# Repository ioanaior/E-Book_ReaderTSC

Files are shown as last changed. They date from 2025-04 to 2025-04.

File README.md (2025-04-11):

# E-Book_ReaderTSC

## 📘 Schema bloc

```mermaid
flowchart TB
  USB-C -->|5V| Charger["Battery Charger (MCP73832)"]
  Charger -->|Charging| LiPo["LiPo Battery"]
  LiPo --> LDO["3V3 LDO"]
  LiPo --> DC5["5V DC/DC"]

  ESP32["ESP32-C3-WROOM"]

  LDO -->|3.3V| ESP32
  LDO -->|3.3V| Display
  LDO -->|3.3V| SDCard
  LDO -->|3.3V| TempSensor
  LDO -->|3.3V| Buttons

  ESP32 -- SPI --> Display["1.5'' E-Ink Display (200x200px)"]
  ESP32 -- SPI --> SDCard["SD Card"]
  ESP32 -- GPIO --> Buttons["Buttons (3x)"]
  ESP32 -- I2C --> TempSensor["Temp/RH Sensor (BME680)"]
  ESP32 -- USB --> USB-C
```

# List of Components

Aici sunt listate componentele, impreuna cu linkurile pentru a verifica preturile si fisele tehnice. Unele componente nu au un model specificat, si în acele cazuri, fisele tehnice si linkurile catre preturi sunt marcate ca `#N/A`.
+ also SJ-ul si TP-urile sunt modelate de mine, deci nu am importat model 3D.

| Name of component  | Device | Check Prices | DataSheet |
|---|---|---|---|
| BOOT_BUTTON | BUTTON_CUSYOMV1 | [Check Price](https://industry.panasonic.com/global/en/products/control/switch/light-touch/number/evqpuj02k)  | [DataSheet](https://industry.panasonic.com/global/en/products/control/switch/light-touch/number/evqpuj02k) |
| C1 | ESP32_WROVER_EAGLE-LTSPICE_CC0402 | [Check Price](https://industry.panasonic.com/global/en/products/control/switch/light-touch/number/evqpuj02k)  | [DataSheet](https://industry.panasonic.com/global/en/products/control/switch/light-touch/number/evqpuj02k) |
| C1_BAT | ESP32_WROVER_EAGLE-LTSPICE_CC0402 | #N/A | #N/A |
| C1_BAT1 | EAGLE-LTSPICE_CC0402 | #N/A | #N/A |
| C1_BAT2 | EAGLE-LTSPICE_CC0402 | #N/A | #N/A |
| C2 | ESP32_WROVER_EAGLE-LTSPICE_CC0402 | #N/A | #N/A |
| C2_BAT | ESP32_WROVER_EAGLE-LTSPICE_CC0402 | #N/A | #N/A |
| C3 | RCL_CPOL-EUCT3528 | #N/A | #N/A |
| C4 | ESP32_WROVER_EAGLE-LTSPICE_CC0402 | #N/A | #N/A |
| C4_USB | ESP32_WROVER_EAGLE-LTSPICE_CC0402 | #N/A | #N/A |
| C5 | ESP32_WROVER_EAGLE-LTSPICE_CC0402 | #N/A | #N/A |
| C5_USB | ESP32_WROVER_EAGLE-LTSPICE_CC0402 | #N/A | #N/A |
| C6 | ESP32_WROVER_EAGLE-LTSPICE_CC0402 | #N/A | #N/A |
| C7 | ESP32_WROVER_EAGLE-LTSPICE_CC0402 | #N/A | #N/A |
| C8 | ESP32_WROVER_EAGLE-LTSPICE_CC0402 | #N/A | #N/A |
| C9 | EAGLE-LTSPICE_CC0402 | #N/A | #N/A |
| C10 | ESP32_WROVER_EAGLE-LTSPICE_CC0402 | #N/A | #N/A |
| C10_SUPERCAP | CPH3225A | [Check Price](https://www.snapeda.com/parts/CPH3225A/Seiko+Instruments/view-part/?ref=eda) | [DataSheet](https://www.snapeda.com/parts/CPH3225A/Seiko+Instruments/view-part/?ref=eda) |
| CHANGE_BUTTON | BUTTON_CUSYOMV1 | [Check Price](https://industry.panasonic.com/global/en/products/control/switch-light-touch/number/evqpuj02k)  | [DataSheet](https://industry.panasonic.com/global/en/products/control/switch-light-touch/number/evqpuj02k) |
| CHG_LED | ADAFRUIT_LEDCHIP-LED0603 | [Check Price](https://www.snapeda.com/parts/KP-1608SURCK/Kingbright/view-part/?ref=search&t=LED%200603) | [DataSheet](https://www.snapeda.com/parts/KP-1608SURCK/Kingbright/view-part/?ref=search&t=LED%200603) |
| C_DELAY | ESP32_WROVER_EAGLE-LTSPICE_CC0402 | #N/A | #N/A |
| D1 | USBLC6-2SC6Y | [Check Price](https://www.snapeda.com/parts/USBLC6-2SC6Y/STMicroelectronics/view-part/?ref=eda) | [DataSheet](https://www.snapeda.com/parts/USBLC6-2SC6Y/STMicroelectronics/view-part/?ref=eda) |
| D2 | ESP32_WROVER_AVX---SD0805S020S1R0_AVX_... | [Check Price](https://eu.mouser.com/ProductDetail/KYOCERA-AVX/SD0805S020S1R0?qs=jCA%252BPfw4LHbpkAoSnwrdjw%3D%3D) | [DataSheet](http://datasheets.avx.com/schottky.pdf) |
| D3 | MBR0530 | [Check Price](https://eu.mouser.com/ProductDetail/KYOCERA-AVX/SD0805S020S1R0?qs=jCA%252BPfw4LHbpkAoSnwrdjw%3D%3D) | [DataSheet](https://eu.mouser.com/ProductDetail/KYOCERA-AVX/SD0805S020S1R0?qs=jCA%252BPfw4LHbpkAoSnwrdjw%3D%3D) |
| D4 | MBR0530 | [Check Price](https://www.snapeda.com/parts/MBR0530/Onsemi/view-part/?ref=eda) | [DataSheet](https://www.snapeda.com/parts/MBR0530/Onsemi/view-part/?ref=eda) |
| D5 | MBR0530 | [Check Price](https://www.snapeda.com/parts/MBR0530/Onsemi/view-part/?ref=eda) | [DataSheet](https://www.snapeda.com/parts/MBR0530/Onsemi/view-part/?ref=eda) |
| D6 | PGB1010603MR | [Check Price](https://www.snapeda.com/parts/PGB1010603MR/Littelfuse/view-part/?ref=eda) | [DataSheet](https://www.snapeda.com/parts/PGB1010603MR/Littelfuse/view-part/?ref=eda) |
| D7 | ESP32_WROVER_AVX---SD0805S020S1R0_AVX_... | [Check Price](https://eu.mouser.com/ProductDetail/KYOCERA-AVX/SD0805S020S1R0?qs=jCA%252BPfw4LHbpkAoSnwrdjw%3D%3D) | [DataSheet](http://datasheets.avx.com/schottky.pdf) |
| D8 | PGB1010603MR | [Check Price](https://www.snapeda.com/parts/PGB1010603MR/Littelfuse/view-part/?ref=eda) | [DataSheet](https://www.snapeda.com/parts/PGB1010603MR/Littelfuse/view-part/?ref=eda) |
| D9 | PGB1010603MR | [Check Price](https://www.snapeda.com/parts/PGB1010603MR/Littelfuse/view-part/?ref=eda) | [DataSheet](https://www.snapeda.com/parts/PGB1010603MR/Littelfuse/view-part/?ref=eda) |
| D10 | PGB1010603MR | [Check Price](https://www.snapeda.com/parts/PGB1010603MR/Littelfuse/view-part/?ref=eda) | [DataSheet](https://www.snapeda.com/parts/PGB1010603MR/Littelfuse/view-part/?ref=eda) |
| D11 | PGB1010603MR | [Check Price](https://www.snapeda.com/parts/PGB1010603MR/Littelfuse/view-part/?ref=eda) | [DataSheet](https://www.snapeda.com/parts/PGB1010603MR/Littelfuse/view-part/?ref=eda) |
| D12 | PGB1010603MR | [Check Price](https://www.snapeda.com/parts/PGB1010603MR/Littelfuse/view-part/?ref=eda) | [DataSheet](https://www.snapeda.com/parts/PGB1010603MR/Littelfuse/view-part/?ref=eda) |
| EPD_C1 | ESP32_WROVER_EAGLE-LTSPICE_CC0402 | #N/A | #N/A |
| EPD_C2 | ESP32_WROVER_EAGLE-LTSPICE_CC0402 | #N/A | #N/A |
| EPD_C5 | ESP32_WROVER_EAGLE-LTSPICE_CC0402 | #N/A | #N/A |
| EPD_C6 | ESP32_WROVER_EAGLE-LTSPICE_CC0402 | #N/A | #N/A |
| EPD_C7 | ESP32_WROVER_EAGLE-LTSPICE_CC0402 | #N/A | #N/A |
| EPD_C8 | ESP32_WROVER_EAGLE-LTSPICE_CC0402 | #N/A | #N/A |
| EPD_C9 | ESP32_WROVER_EAGLE-LTSPICE_CC0402 | #N/A | #N/A |
| EPD_C10 | ESP32_WROVER_EAGLE-LTSPICE_CC0402 | #N/A | #N/A |
| EPD_C11 | ESP32_WROVER_EAGLE-LTSPICE_CC0402 | #N/A | #N/A |
| EPD_C12 | ESP32_WROVER_EAGLE-LTSPICE_CC0402 | #N/A | #N/A |
| IC1 | BD5229G-TR | [Check Price](https://componentsearchengine.com/part-view/BD5229G-TR/ROHM%20Semiconductor) | [DataSheet](https://componentsearchengine.com/part-view/BD5229G-TR/ROHM%20Semiconductor) |
| IC4 | XC6220A331MR-G | [Check Price](https://componentsearchengine.com/part-view/XC6220A331MR-G/Torex) | [DataSheet](https://componentsearchengine.com/part-view/XC6220A331MR-G/Torex) |
| J1 | FH34SRJ-24S-0.5SH_99_ | [Check Price](https://componentsearchengine.com/part-view/XC6220A331MR-G/Torex) | [DataSheet](https://componentsearchengine.com/part-view/XC6220A331MR-G/Torex) |
| J2 | SAMACSYS_PARTS_USB4110-GF-A | [Check Price](https://componentsearchengine.com/part-view/USB4110-GF-A/GCT%20(GLOBAL%20CONNECTOR%20TECHNOLOGY)) | [DataSheet](https://componentsearchengine.com/part-view/USB4110-GF-A/GCT%20(GLOBAL%20CONNECTOR%20TECHNOLOGY)) |
| J3 | QWIIC_CONNECTORJS-1MM | #N/A | #N/A |
| J4 | 112A-TAAR-R03_ATTEND | [Check Price](https://store.comet.srl.ro/Catalogue/Product/43497/) | [DataSheet](https://store.comet.srl.ro/Catalogue/Product/43497/) |
| L1 | 744043680IND_4828-WE-TPC_WRE | [Check Price](https://eu.mouser.com/ProductDetail/Wurth-Elektronik/744043680?qs=PGXP4M47uW6VkZq%252BkzjrHA%3D%3D) | [DataSheet](https://eu.mouser.com/ProductDetail/Wurth-Elektronik/744043680?qs=PGXP4M47uW6VkZq%252BkzjrHA%3D%3D) |
| PFMF.050.1 | ESP32C6_VARISTORCN1812 | [Check Price](https://www.mouser.co.uk/ProductDetail/EPCOS-TDK/B72520T0350K062?qs=dEfas%2FXlABIszF52uu7vrg%3D%3D) | [DataSheet](https://www.mouser.co.uk/ProductDetail/EPCOS-TDK/B72520T0350K062?qs=dEfas%2FXlABIszF52uu7vrg%3D%3D) |
| Q1 | ESP32_WROVER_SPARKFUN-DISCRETESEMI_MOSFET_... | [Check Price](https://componentsearchengine.com/part-view/DMG2305UX-7/Diodes%20Incorporated) | [DataSheet](https://componentsearchengine.com/part-view/DMG2305UX-7/Diodes%20Incorporated) |
| Q2 | ESP32_WROVER_SPARKFUN-DISCRETESEMI_MOSFET_... | #N/A | #N/A |
| Q3 | D8 | [Check Price](https://componentsearchengine.com/part-view/PGB1010603MR/Littelfuse) | [DataSheet](https://componentsearchengine.com/part-view/PGB1010603MR/Littelfuse) |
| Q4 | Q2_TS-B2_REACHPACK | #N/A | #N/A |

Detalii despre functionalitatea hardware

### Microcontroller – ESP32-C3-WROOM
Microcontroller-ul utilizat este ESP32-C3-WROOM, un procesor 32-bit RISC-V, care ruleaza la frecvente de pana la 160MHz. Acesta dispune de 512KB de SRAM intern si 8MB de flash extern, suficiente pentru a sustine aplicatii complexe. ESP32-C3-WROOM beneficiaza de conectivitate Wi-Fi 6 si Bluetooth 5, facilitand conexiuni rapide si stabile. Printre perifericele sale se numara SPI, I²C, UART si GPIO multiple, iar pentru economisirea energiei, dispune de moduri de tip sleep si deep sleep.

### Ecran E-Paper (1.5 inch)
Ecranul e-paper utilizat are o rezolutie de 200x200px si comunica cu ESP32 prin interfata SPI cu 4 pini (CS, DC, RST, BUSY). Desi consumul de energie este foarte redus in timpul afisarii statice, la fiecare refresh al imaginii ecranul necesita aproximativ 15–25mA, in functie de modul de actualizare ales. Acest tip de afisaj este ideal pentru aplicatiile de tip e-reader, datorita consumului minim de energie in mod static.

### Senzor de mediu – BME680
Senzorul BME680 masoara temperatura, umiditatea, presiunea si calitatea aerului (VOC/eCO2). Acesta comunica cu microcontroller-ul prin I²C la 400kHz, iar consumul in modul standby este de doar 2.1µA, crescand pana la cativa mA in timpul masurarilor. BME680 este o alegere excelenta datorita capacitatii sale de a integra multiple tipuri de masuratori intr-un singur cip, oferind date importante pentru monitorizarea mediului.

### Gestionarea energiei – Baterie Li-Po si IC de incarcare
Dispozitivul este alimentat de o baterie Li-Po de 2500mAh, care ofera o autonomie extinsa. IC-ul de incarcare MCP73832, compatibil cu incarcarea prin USB-C, permite incarcarea bateriei cu un curent de pana la 1A. Monitorizarea nivelului bateriei se face prin intermediul unui fuel gauge MAX17048, care transmite informatii despre tensiune si stare prin I²C. Pentru a asigura o tensiune stabila de 3.3V, se foloseste un regulator LDO XC6220A331MR-G, care alimenteaza microcontroller-ul si celelalte componente.

### Butoane tactile pentru interactiune
Dispozitivul dispune de trei butoane tactile pentru navigarea prin meniu, selectarea optiunilor si schimbarea paginilor. Fiecare buton este conectat la un GPIO al microcontroller-ului printr-un circuit de debouncing, care asigura o interactiune fiabila. Debouncing-ul poate fi implementat fie hardware, printr-o combinatie de rezistor si condensator, fie in firmware.

### Port USB-C
Portul USB-C permite atat incarcarea bateriei, cat si transferul de date. Acesta poate fi utilizat si pentru actualizari de firmware prin bootloader sau OTA prin Wi-Fi. Protectiile incluse (ESD si rezistente de terminare) asigura o protectie suplimentara impotriva eventualelor probleme de conectivitate.

### Conector Qwiic (I²C)
Conectorul Qwiic standardizat, cu patru pini (VCC, GND, SDA, SCL), faciliteaza integrarea rapida a modulelor I²C externe. Acesta este ideal pentru extinderea dispozitivului cu senzori suplimentari sau pentru prototipuri rapide.

### Card SD pentru stocare externa
Dispozitivul include un conector pentru card SD, permitand stocarea de e-book-uri, loguri sau fisiere pentru actualizari de firmware. Interfata poate fi configurata in modul SD (1-bit/4-bit) sau SPI, in functie de necesitatile firmware-ului.

### RTC DS3231
RTC-ul DS3231 asigura un ceas de timp real precis si mentine timpul chiar si atunci cand dispozitivul nu este alimentat, datorita unei baterii secundare sau supercondensatorului de backup. Comunicarea cu microcontroller-ul se face prin I²C.

### Memorie externa Flash (W25Q512JVEIQ)
Memoria flash externa W25Q512JVEIQ, conectata prin SPI dedicat (quad SPI), este utilizata pentru stocarea firmware-ului si a fisierelor mari (e-book-uri, etc.). Acesta permite o incarcare rapida a datelor si o capacitate mare de stocare.

### Comunicare si interfete
Dispozitivul utilizeaza diverse interfete pentru a comunica cu componentele sale:

- **SPI**: Ecranul e-paper si memoria flash externa utilizeaza SPI pentru comunicare.
- **I²C**: Senzorul BME680, fuel gauge MAX17048, RTC DS3231 si conectorul Qwiic sunt conectate prin I²C.
- **USB-C**: Transfer de date si alimentare.
- **GPIO**: Butoane tactile si semnale de control pentru display.

### Estimarea consumului de energie
- **ESP32-C3-WROOM** (activ): ~80mA (Wi-Fi activ) / < 10mA (idle)
- **E-Paper (refresh)**: ~15–25mA (doar in timpul refresh-ului)
- **BME680** (activ): ~3.6mA (peak) / 2.1µA (sleep)
- **MAX17048 (fuel gauge)**: ~50µA
- **DS3231 (RTC)**: ~3.5mA (activ) / <1µA (back-up)
- **MCP73832 (charger)**: Depinde de curentul de incarcare

In modul Deep Sleep, consumul total scade sub 50-100µA, iar in utilizare activa cu Wi-Fi si actualizari frecvente ale ecranului, consumul poate ajunge la 100-150mA.

Cu o baterie de 2500mAh, dispozitivul poate avea o autonomie de cateva saptamani in regim normal de utilizare, in care majoritatea timpului este in stare inactiva si doar afiseaza imagini statice.

## Detalierea pinilor ESP32-C6 utilizati pentru fiecare componenta

| Pin ESP32-C6  | Componenta / Semnal | Explicatie |
|---|---|---|
| GPIO1 | I²C SDA (BME688, MAX17048, DS3231, Qwiic) | Se foloseste pentru a partaja magistrala I²C intre toti senzorii si RTC. |
| GPIO2 | I²C SCL (BME688, MAX17048, DS3231, Qwiic) | Linia de clock pentru comunicarea I²C. |
| GPIO5 | SPI MISO (E-Paper) | Pinul pentru citirea datelor sau a statusului de la ecranul e-paper. |
| GPIO6 | SPI MOSI (E-Paper) | Trimiterea datelor catre ecranul e-paper. |
| GPIO7 | SPI CLK (E-Paper) | Semnal de clock pentru sincronizarea cu e-paper. |
| GPIO8 | SPI CS (E-Paper) | Chip Select pentru a activa comunicarea cu e-paper.  |
| GPIO9 | E-Paper DC (Data/Command) | Semnal pentru a diferentia intre date si comenzi pentru ecranul e-paper. |
| GPIO10 | E-Paper RST | Pinul de reset hardware pentru e-paper. |
| GPIO11 | E-Paper BUSY | Intrare din display care indica daca ecranul este ocupat sau nu. |
| GPIO12 | Button #1 | Intrare digitala pentru primul buton (ex. pagina urmatoare). |
| GPIO13 | Button #2 | Intrare digitala pentru al doilea buton (ex. pagina anterioara). |
| GPIO14 | Button #3 | Intrare digitala pentru al treilea buton (ex. Meniu/OK). |
| GPIO15 | MAX17048 ALERT (optional) | Semnal de alerta de la MAX17048 pentru nivel scazut al bateriei. |
| GPIO16 | USB D+ (intern la USB PHY) | Pin dedicat pentru semnalul USB 2.0 (D+). |
| GPIO17 | USB D- (intern la USB PHY) | Pin dedicat pentru semnalul USB 2.0 (D-). |
| GPIO18 | LED de status (optional) | Indicator pentru diverse stari (ex. Wi-Fi, incarcare, etc.). |
| GPIO19 | SD Card CS (optional) | Chip Select pentru cardul SD (daca se foloseste SPI). |
| GPIO20 | SD Card MISO (optional) | Intrare date de la cardul SD. |
| GPIO21 | SD Card MOSI (optional) | Iesire date catre cardul SD. |
| GPIO4 | SD Card CLK (optional) | Semnal de clock pentru cardul SD (SPI). |

## Concluzii

Acest proiect a fost un adevarat challenge si a implicat o cantitate considerabila de munca. Au existat momente cand m-am simtit complet depasita, iar uneori chiar enervata de complexitatea sa :)) Cu toate acestea, am reusit sa-l finalizez si sunt destul de multumita de rezultat. 
Sper ca totul este in regula si ca nu mi-a scapat vreun detaliu prea important. Ca orice proiect de acest tip, a fost o experienta de invatare continua, iar daca voi gasi ceva ce nu am luat in considerare, il voi imbunatati pe parcurs.😅<3

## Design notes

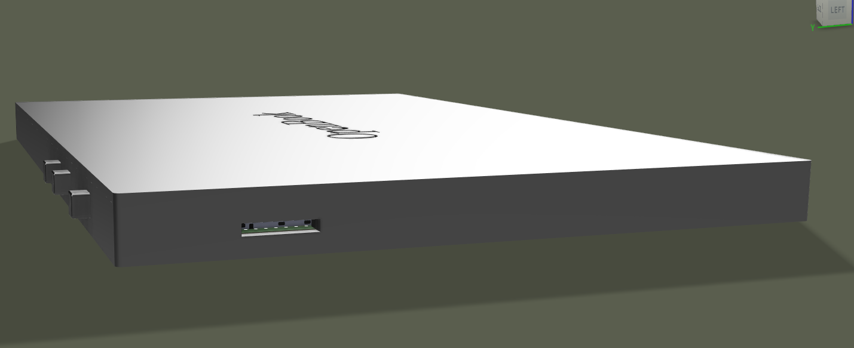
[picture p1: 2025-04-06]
Images/Screenshot 2025-04-06 160244.png

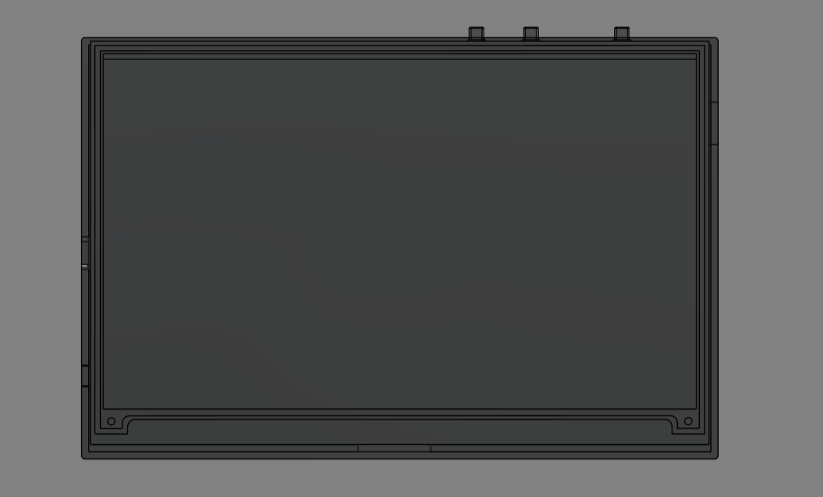
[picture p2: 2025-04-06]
Images/Screenshot 2025-04-06 160750.png

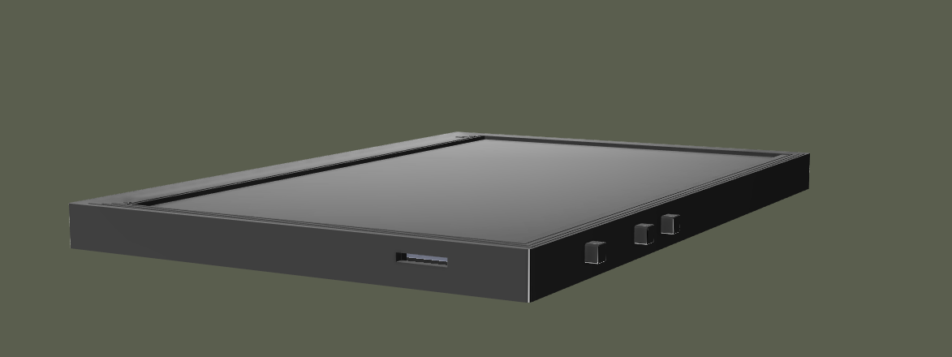
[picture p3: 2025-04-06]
Images/Screenshot 2025-04-06 160951.png

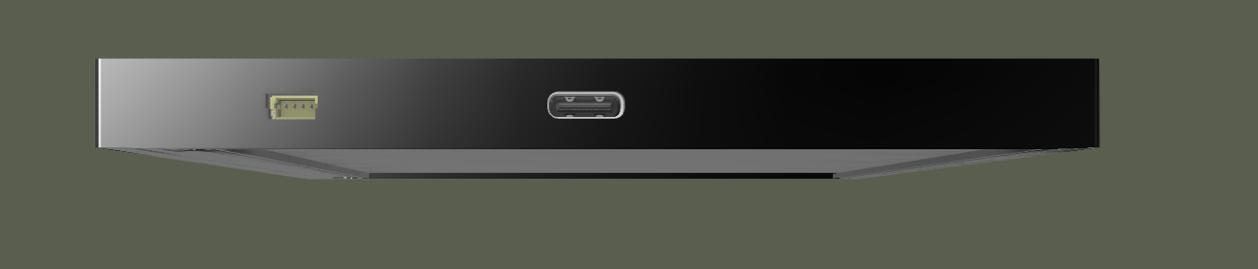
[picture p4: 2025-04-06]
Images/Screenshot 2025-04-06 160404.png

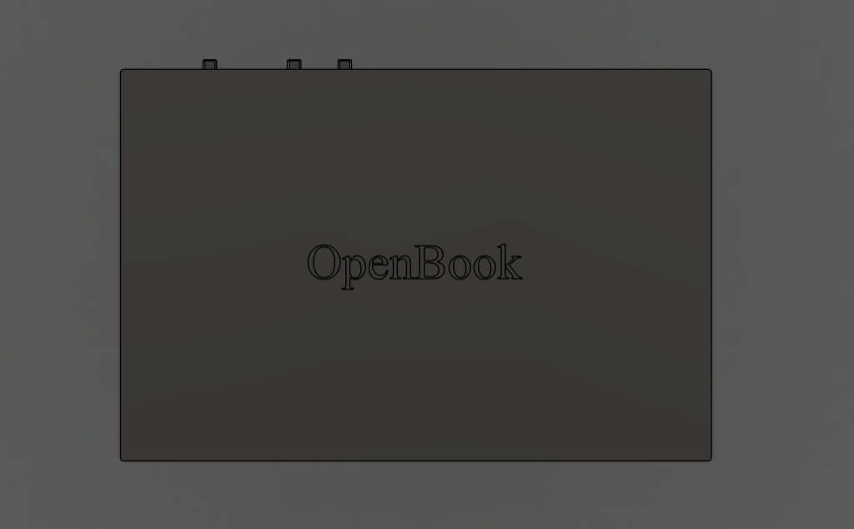
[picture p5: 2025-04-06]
Images/Screenshot 2025-04-06 160526.png

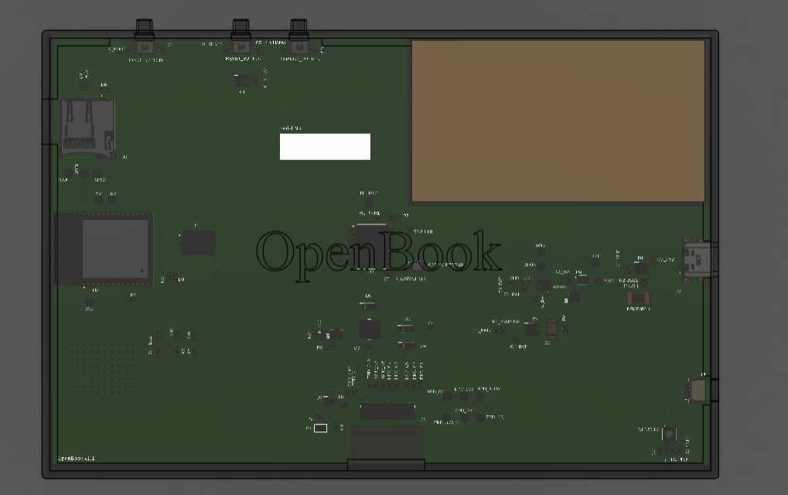
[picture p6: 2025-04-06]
Images/Screenshot 2025-04-06 160657.png

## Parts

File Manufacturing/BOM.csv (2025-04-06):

Qty | Value | Device | Package | Parts | Description | ARROW_PART_NUMBER | ARROW_PRICE-STOCK | ATR | AVAILABILITY | CENTROID_NOT_SPECIFIED | CHECK_PRICES | COPYRIGHT | DATASHEET | DESCRIPTION | DIGIKEY_DESCRIPTION | DIGIKEY_PART_NUMBER | HEIGHT | LEAD_FREE | MANUFACTURER_NAME | MANUFACTURER_PART_NUMBER | MF | MFR_NAME | MOUSER_PART_NUMBER | MOUSER_PRICE-STOCK | MOUSER_TESTING_PART_NUMBER | MOUSER_TESTING_PRICE-STOCK | MP | MPN | PACKAGE | POPULARITY | PREFIX | PRICE | PROD_ID | PURCHASE-URL | ROHS | SNAPEDA_LINK | SPICEPREFIX | TEMPERATURE_RANGE_HIGH | TEMPERATURE_RANGE_LOW | VALUE
1 |  | ADAFRUIT_LEDCHIP-LED0603 | ADAFRUIT_CHIP-LED0603 | CHG_LED | LED
1 |  | SJ | SJ | SJ1 | SMD solder JUMPER |  |  |  |  |  |  |  |  |  |  |  |  |  |  |  |  |  |  |  |  |  |  |  |  | 3
1 | 0.47 | ESP32_WROVER_EAGLE-LTSPICE_RR0402 | ESP32_WROVER_EAGLE-LTSPICE_R0402 | R3 | RESISTOR, European symbol
1 | 100K | ESP32_WROVER_EAGLE-LTSPICE_RR0402 | ESP32_WROVER_EAGLE-LTSPICE_R0402 | R1_PWRUSB | RESISTOR, European symbol
8 | 100nF | EAGLE-LTSPICE_C | EAGLE-LTSPICE_C0402 | C1, C2, C4_USB, C6, C8, C9, C10, C_DELAY | CAPACITOR, European symbol
1 | 100uF | RCL_CPOL-EUCT3528 | RCL_CT3528 | C3 | POLARIZED CAPACITOR, European symbol |  |  |  |  |  |  |  |  |  |  |  |  |  |  |  |  |  |  |  |  |  |  |  |  | 0 |  |  |  |  |  |  | C
16 | 10K | ESP32_WROVER_EAGLE-LTSPICE_RR0402 | ESP32_WROVER_EAGLE-LTSPICE_R0402 | R1, R1-PINH, R1-PINH1, R2-PINH, R2-PINH1, R4, R5, R6, R7, R8, R9, R10, R_BOOT, R_CHANGE, R_CL1, R_RESET | RESISTOR, European symbol
1 | 10uF | EAGLE-LTSPICE_C | EAGLE-LTSPICE_C0402 | C7 | CAPACITOR, European symbol
1 | 112A-TAAR-R03_ATTEND | 112A-TAAR-R03_ATTEND | 112ATAARR03ATTEND | J4 | Micro SD Card Socket, Push-Push Type, Top Mount, SMT, H=1.83mm, 10u |  |  |  |  |  |  |  |  | Micro SD Card Socket | Push-Push Type | Top Mount | SMT | H=1.83mm | 10u |  |  | 1.9mm |  | ATTEND | 112A-TAAR-R03 ATTEND
1 | 15 | ESP32_WROVER_EAGLE-LTSPICE_RR0402 | ESP32_WROVER_EAGLE-LTSPICE_R0402 | R_CAPACITOR | RESISTOR, European symbol
1 | 1uF | EAGLE-LTSPICE_C | EAGLE-LTSPICE_C0402 | C5 | CAPACITOR, European symbol
10 | 1uF/50V | EAGLE-LTSPICE_C | EAGLE-LTSPICE_C0402 | EPD_C1, EPD_C2, EPD_C5, EPD_C6, EPD_C7, EPD_C8, EPD_C9, EPD_C10, EPD_C11, EPD_C12 | CAPACITOR, European symbol
1 | 2.2 | ESP32_WROVER_EAGLE-LTSPICE_RR0402 | ESP32_WROVER_EAGLE-LTSPICE_R0402 | R2 | RESISTOR, European symbol
1 | 200 | ESP32_WROVER_EAGLE-LTSPICE_RR0402 | ESP32_WROVER_EAGLE-LTSPICE_R0402 | R1_BAT | RESISTOR, European symbol
2 | 20V/4.2A/52m?/1.4W | ESP32_WROVER_SPARKFUN-DISCRETESEMI_MOSFET_PCH-DMG2305UX-7 | ESP32_WROVER_SPARKFUN-DISCRETESEMI_SOT23-3 | Q1, Q2 | P-channel MOSFETs |  |  | DMG2305UX-7 |  |  |  |  |  |  |  |  |  |  |  |  |  |  |  |  |  |  |  |  |  |  |  |  | TRAN-14388 |  |  |  |  |  |  | 20V/4.2A/52m?/1.4W
1 | 2K | ESP32_WROVER_EAGLE-LTSPICE_RR0402 | ESP32_WROVER_EAGLE-LTSPICE_R0402 | R2_BAT | RESISTOR, European symbol
5 | 4.7uF | EAGLE-LTSPICE_C | EAGLE-LTSPICE_C0402 | C1_BAT, C1_BAT1, C1_BAT2, C2_BAT, C5_USB | CAPACITOR, European symbol
1 | 4.7uF/25V | EAGLE-LTSPICE_C | EAGLE-LTSPICE_C0402 | C4 | CAPACITOR, European symbol
2 | 5k1 | ESP32_WROVER_EAGLE-LTSPICE_RR0402 | ESP32_WROVER_EAGLE-LTSPICE_R0402 | R2-USB, R2-USB1 | RESISTOR, European symbol
1 | 68uH | 744043680IND_4828-WE-TPC_WRE | IND_4828-WE-TPC_WRE | L1 |  |  |  |  |  |  |  | Copyright (C) 2024 Ultra Librarian. All rights reserved. |  |  |  |  |  |  |  | 744043680 |  | Wurth Electronics
1 | BD5229G-TR | BD5229G-TR | SOT95P280X125-5N | IC1 | Voltage Detector with Adjustable Delay Time: CMOS processes are utilized to develop high precision, low current consumption CMOS reset ICs that allow arbitrary setting of the delay time. The extensive lineup includes both Nch Open Drain and CMOS output types in a wide range of detection voltages (from 2.3V to 6.0V, in 0.1V steps), enabling selection of the ideal solution based on customer requirements. In addition, the entire series is of course both lead-free and RoHS-compliant. |  |  |  |  |  |  |  |  | Voltage Detector with Adjustable Delay Time: CMOS processes are utilized to develop high precision | low current consumption CMOS reset ICs that allow arbitrary setting of the delay time. The extensive lineup includes both Nch Open Drain and CMOS output types in a wide range of detection voltages (from 2.3V to 6.0V | in 0.1V steps) | enabling selection of the ideal solution based on customer requirements. In addition | the entire series is of course both lead-free and RoHS-compliant. |  |  | 1.25mm |  | ROHM Semiconductor | BD5229G-TR |  |  | 755-BD5229G-TR | https://www.mouser.co.uk/ProductDetail/ROHM-Semiconductor/BD5229G-TR?qs=4kLU8WoGk0vvnhrrYwdszw%3D%3D
3 | BUTTON_CUSYOMV1. | BUTTON_CUSYOMV1. | MYBUTTON | BOOT_BUTTON, CHANGE_BUTTON, RESET_BUTTON
1 | CPH3225A | CPH3225A | CAPCP3225X100N | C10_SUPERCAP | Cap 0.011F 3.3V 1210 Flat Check availability |  |  |  | Not in stock |  | https://www.snapeda.com/parts/CPH3225A/Seiko+Instruments/view-part/?ref=eda |  |  | 11 mF (EDLC) Supercapacitor 3.3 V 1210 (3225 Metric) - - |  |  |  |  |  |  | Seiko Instruments |  |  |  |  |  | CPH3225A |  | 1210 Seiko |  |  | None |  | https://www.snapeda.com/api/url_track_click_mouser/?unipart_id=562593&manufacturer=Seiko Instruments&part_name=CPH3225A&search_term=None |  | https://www.snapeda.com/parts/CPH3225A/Seiko+Instruments/view-part/?ref=snap
1 | DS3231SN# | DS3231SN# | SOIC127P1032X265-16N | U3 | Real Time Clock Serial 16-Pin SOIC W T/R Check availability |  |  |  | In Stock |  | https://www.snapeda.com/parts/DS3231SN%23/Analog+Devices/view-part/?ref=eda |  |  | Extremely Accurate I2C-Integrated RTC/TCXO/Crystal |  |  |  |  |  |  | Analog Devices |  |  |  |  |  | DS3231SN# |  | SOIC-16 Maxim |  |  | None |  | https://www.snapeda.com/api/url_track_click_mouser/?unipart_id=99048&manufacturer=Analog Devices&part_name=DS3231SN#&search_term=None |  | https://www.snapeda.com/parts/DS3231SN%23/Analog+Devices/view-part/?ref=snap
1 | ESP32-C6-WROOM-1-N8 | ESP32-C6-WROOM-1-N8 | XCVR_ESP32-C6-WROOM-1-N8 | U2 | Check availability |  |  |  | In Stock |  | https://www.snapeda.com/parts/ESP32-C6-WROOM-1-N8/Espressif+Systems/view-part/?ref=eda |  |  | Multiprotocol Modules ESP32-C6 module | Wi-Fi 6 in 2.4 GHz band | Bluetooth 5 | Zigbee 3.0 and Thread. ESP34-WROOM Compatible - ENGINEERING SAMPLE |  |  |  |  |  |  | Espressif Systems |  |  |  |  |  | ESP32-C6-WROOM-1-N8 |  | None |  |  | None |  |  |  | https://www.snapeda.com/parts/ESP32-C6-WROOM-1-N8/Espressif+Systems/view-part/?ref=snap
1 | ESP32C6_VARISTORCN1812 | ESP32C6_VARISTORCN1812 | ESP32C6_VARISTOR_CT/CN1812 | PFMF.050.1 | VARISTOR |  |  |  |  |  |  |  |  |  |  |  |  |  |  |  |  |  |  |  |  |  |  |  |  | 0
2 | ESP32_WROVER_AVX---SD0805S020S1R0_AVX_SD0805S020S1R0_0_0AVX_SD0805S020S1R0_0_0 | ESP32_WROVER_AVX---SD0805S020S1R0_AVX_SD0805S020S1R0_0_0AVX_SD0805S020S1R0_0_0 | ESP32_WROVER_AVX---SD0805S020S1R0_AVX_SD0805S020S1R0_0 | D2, D7 | Schottky Barrier Rectifier Diode |  |  | SD0805S020S1R0 |  | No |  |  | http://datasheets.avx.com/schottky.pdf |  | DIODE SCHOTTKY 20V 1A 0805 | 478-7800-1-ND |  | yes |  |  | AVX |  | 581-SD0805S020S1R0 |  |  |  |  |  | 0805 (2012 metric) |  | D |  |  |  | yes |  |  | +125°C | -55°C
1 | ESP32_WROVER_BME680_BME680 | ESP32_WROVER_BME680_BME680 | ESP32_WROVER_BME680_PSON80P300X300X100-8N | SENSOR2 | Integrated Environmental Unit |  |  | BME688 | Unavailable |  |  |  |  | Integrated Environmental Unit |  |  |  |  |  |  | Bosch Sensortec |  |  |  |  |  | BME680 |  | LGA-8 Bosch Tools |  |  | None
1 | ESP32_WROVER_SPARKFUN-IC-POWER_MCP73831 | ESP32_WROVER_SPARKFUN-IC-POWER_MCP73831 | ESP32_WROVER_SPARKFUN-IC-POWER_SOT23-5 | MCP73831 | MCP73831T Li-Ion, Li-Pol Controller |  |  |  |  |  |  |  |  |  |  |  |  |  |  |  |  |  |  |  |  |  |  |  |  |  |  |  | IC-09995
1 | FH34SRJ-24S-0.5SH_99_ | FH34SRJ-24S-0.5SH_99_ | FH34SRJ24S05SH99 | J1 | (0.50mm) Surface Mount, Right Angle |  |  |  |  |  |  |  |  | 24 Position FFC | FPC Connector Contacts | (0.50mm) Surface Mount | Right Angle |  |  | 1.1mm |  | Hirose | FH34SRJ-24S-0.5SH(99) |  |  | 798-FH34SRJ24S05SH99 | https://www.mouser.co.uk/ProductDetail/Hirose-Connector/FH34SRJ-24S-0.5SH99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
1 | MAX17048G+T10 | MAX17048G+T10 | SON50P200X200X80-9N | U4 | Check availability |  |  |  | In Stock |  | https://www.snapeda.com/parts/MAX17048G+T10/Analog+Devices/view-part/?ref=eda |  |  | 3µA 1-Cell/2-Cell Fuel Gauge with ModelGauge |  |  |  |  |  |  | Analog Devices |  |  |  |  |  | MAX17048G+T10 |  | TDFN-8 Maxim |  |  | None |  | https://www.snapeda.com/api/url_track_click_mouser/?unipart_id=329239&manufacturer=Analog Devices&part_name=MAX17048G+T10&search_term=None |  | https://www.snapeda.com/parts/MAX17048G+T10/Analog+Devices/view-part/?ref=snap
3 | MBR0530 | MBR0530 | SOD3716X135N | D3, D4, D5 | ON SEMICONDUCTOR - MBR0530 - DIODE, SCHOTTKY, 0.5A, 30V, SOD-123 |  |  |  | In Stock |  | https://www.snapeda.com/parts/MBR0530/Onsemi/view-part/?ref=eda |  |  | Diode Schottky 30 V 500mA Surface Mount SOD-123 |  |  |  |  |  |  | ON Semiconductor |  |  |  |  |  | MBR0530 |  | SOD-123-2 ON Semiconductor |  |  | None |  | https://www.snapeda.com/api/url_track_click_mouser/?unipart_id=179458&manufacturer=ON Semiconductor&part_name=MBR0530&search_term=None |  | https://www.snapeda.com/parts/MBR0530/Onsemi/view-part/?ref=snap
6 | PGB1010603MR. | PGB1010603MR. | DIOC1608X36N | D6, D8, D9, D10, D11, D12 | Check availability
1 | QWIIC_RIGHT_ANGLE | QWIIC_CONNECTORJS-1MM | JST04_1MM_RA | J3 | SparkFun I2C Standard Qwiic Connector |  |  |  |  |  |  |  |  |  |  |  |  |  |  |  |  |  |  |  |  |  |  |  |  |  |  |  | CONN-13694 |  |  |  |  |  |  | QWIIC_RIGHT_ANGLE
1 | SAMACSYS_PARTS_USB4110-GF-A | SAMACSYS_PARTS_USB4110-GF-A | SAMACSYS_PARTS_USB4110GFA | J2 | CONN USB 2.0 TYPE-C R/A SMT |  |  |  |  |  |  |  |  | CONN USB 2.0 TYPE-C R/A SMT |  |  | 3.26mm |  | GCT (GLOBAL CONNECTOR TECHNOLOGY) | USB4110-GF-A |  |  | 640-USB4110-GF-A | https://www.mouser.co.uk/ProductDetail/GCT/USB4110-GF-A?qs=KUoIvG%2F9IlYiZvIXQjyJeA%3D%3D
1 | SI1308EDL-T1-GE3 | SI1308EDL-T1-GE3 | SOT65P210X110-3N | Q3 | MOSFET N-Ch 30V 1.5A TrenchFET SC70 Vishay Si1308EDL-T1-GE3 N-channel MOSFET Transistor, 1.5 A, 30 V, 3-Pin SC-70 |  |  |  | In Stock |  | https://www.snapeda.com/parts/SI1308EDL-T1-GE3/Vishay+Siliconix/view-part/?ref=eda |  |  | Si1308EDL-T1-GE3 N-channel MOSFET Transistor | 1.5 A | 30 V | 3-Pin SC-70 | Siliconix / Vishay SI1308EDL-T1-GE3 |  |  |  |  |  |  | Vishay Siliconix |  |  |  |  |  | SI1308EDL-T1-GE3 |  | SOT-323 Vishay Semiconductor |  |  | None |  | https://www.snapeda.com/api/url_track_click_mouser/?unipart_id=274603&manufacturer=Vishay Siliconix&part_name=SI1308EDL-T1-GE3&search_term=None |  | https://www.snapeda.com/parts/SI1308EDL-T1-GE3/Vishay+Siliconix/view-part/?ref=snap
17 | TPTP20R | TPTP20R | TP20R | TP1, TP2, TP3, TP4, TP5, TP6, TP7, TP8, TP9, TP10, TP11, TP12, TP13, TP14, TP15, TP16, TP17 | Test pad
1 | USBLC6-2SC6Y | USBLC6-2SC6Y | SOT95P280X145-6N | D1 | Low Cap. ESD Protection Auto SOT-23-6 STMicroelectronics USBLC6-2SC6Y, Dual Uni-Directional TVS Diode Array, 6-Pin SOT-23 |  |  |  | In Stock |  | https://www.snapeda.com/parts/USBLC6-2SC6Y/STMicroelectronics/view-part/?ref=eda |  |  | 17V Clamp 5A (8/20µs) Ipp Tvs Diode Surface Mount SOT-23-6 |  |  |  |  |  |  | STMicroelectronics |  |  |  |  |  | USBLC6-2SC6Y |  | SOT-23-6 STMicroelectronics |  |  | None |  |  |  | https://www.snapeda.com/parts/USBLC6-2SC6Y/STMicroelectronics/view-part/?ref=snap
1 | W25Q512JVEIQ | W25Q512JVEIQ | SON127P600X800X80-9N | U1 | Check availability |  |  |  | In Stock |  | https://www.snapeda.com/parts/W25Q512JVEIQ/Winbond+Electronics/view-part/?ref=eda |  |  | FLASH - NOR Memory IC 512Mb (64M x 8) SPI - Quad I/O 133 MHz 8-WSON (8x6) |  |  |  |  |  |  | Winbond Electronics |  |  |  |  |  | W25Q512JVEIQ |  | Package |  |  | None |  |  |  | https://www.snapeda.com/parts/W25Q512JVEIQ/Winbond+Electronics/view-part/?ref=snap
1 | XC6220A331MR-GIC4 | XC6220A331MR-GIC4 | SOT95P280X120-5N | IC4 | LDO Voltage Regulators

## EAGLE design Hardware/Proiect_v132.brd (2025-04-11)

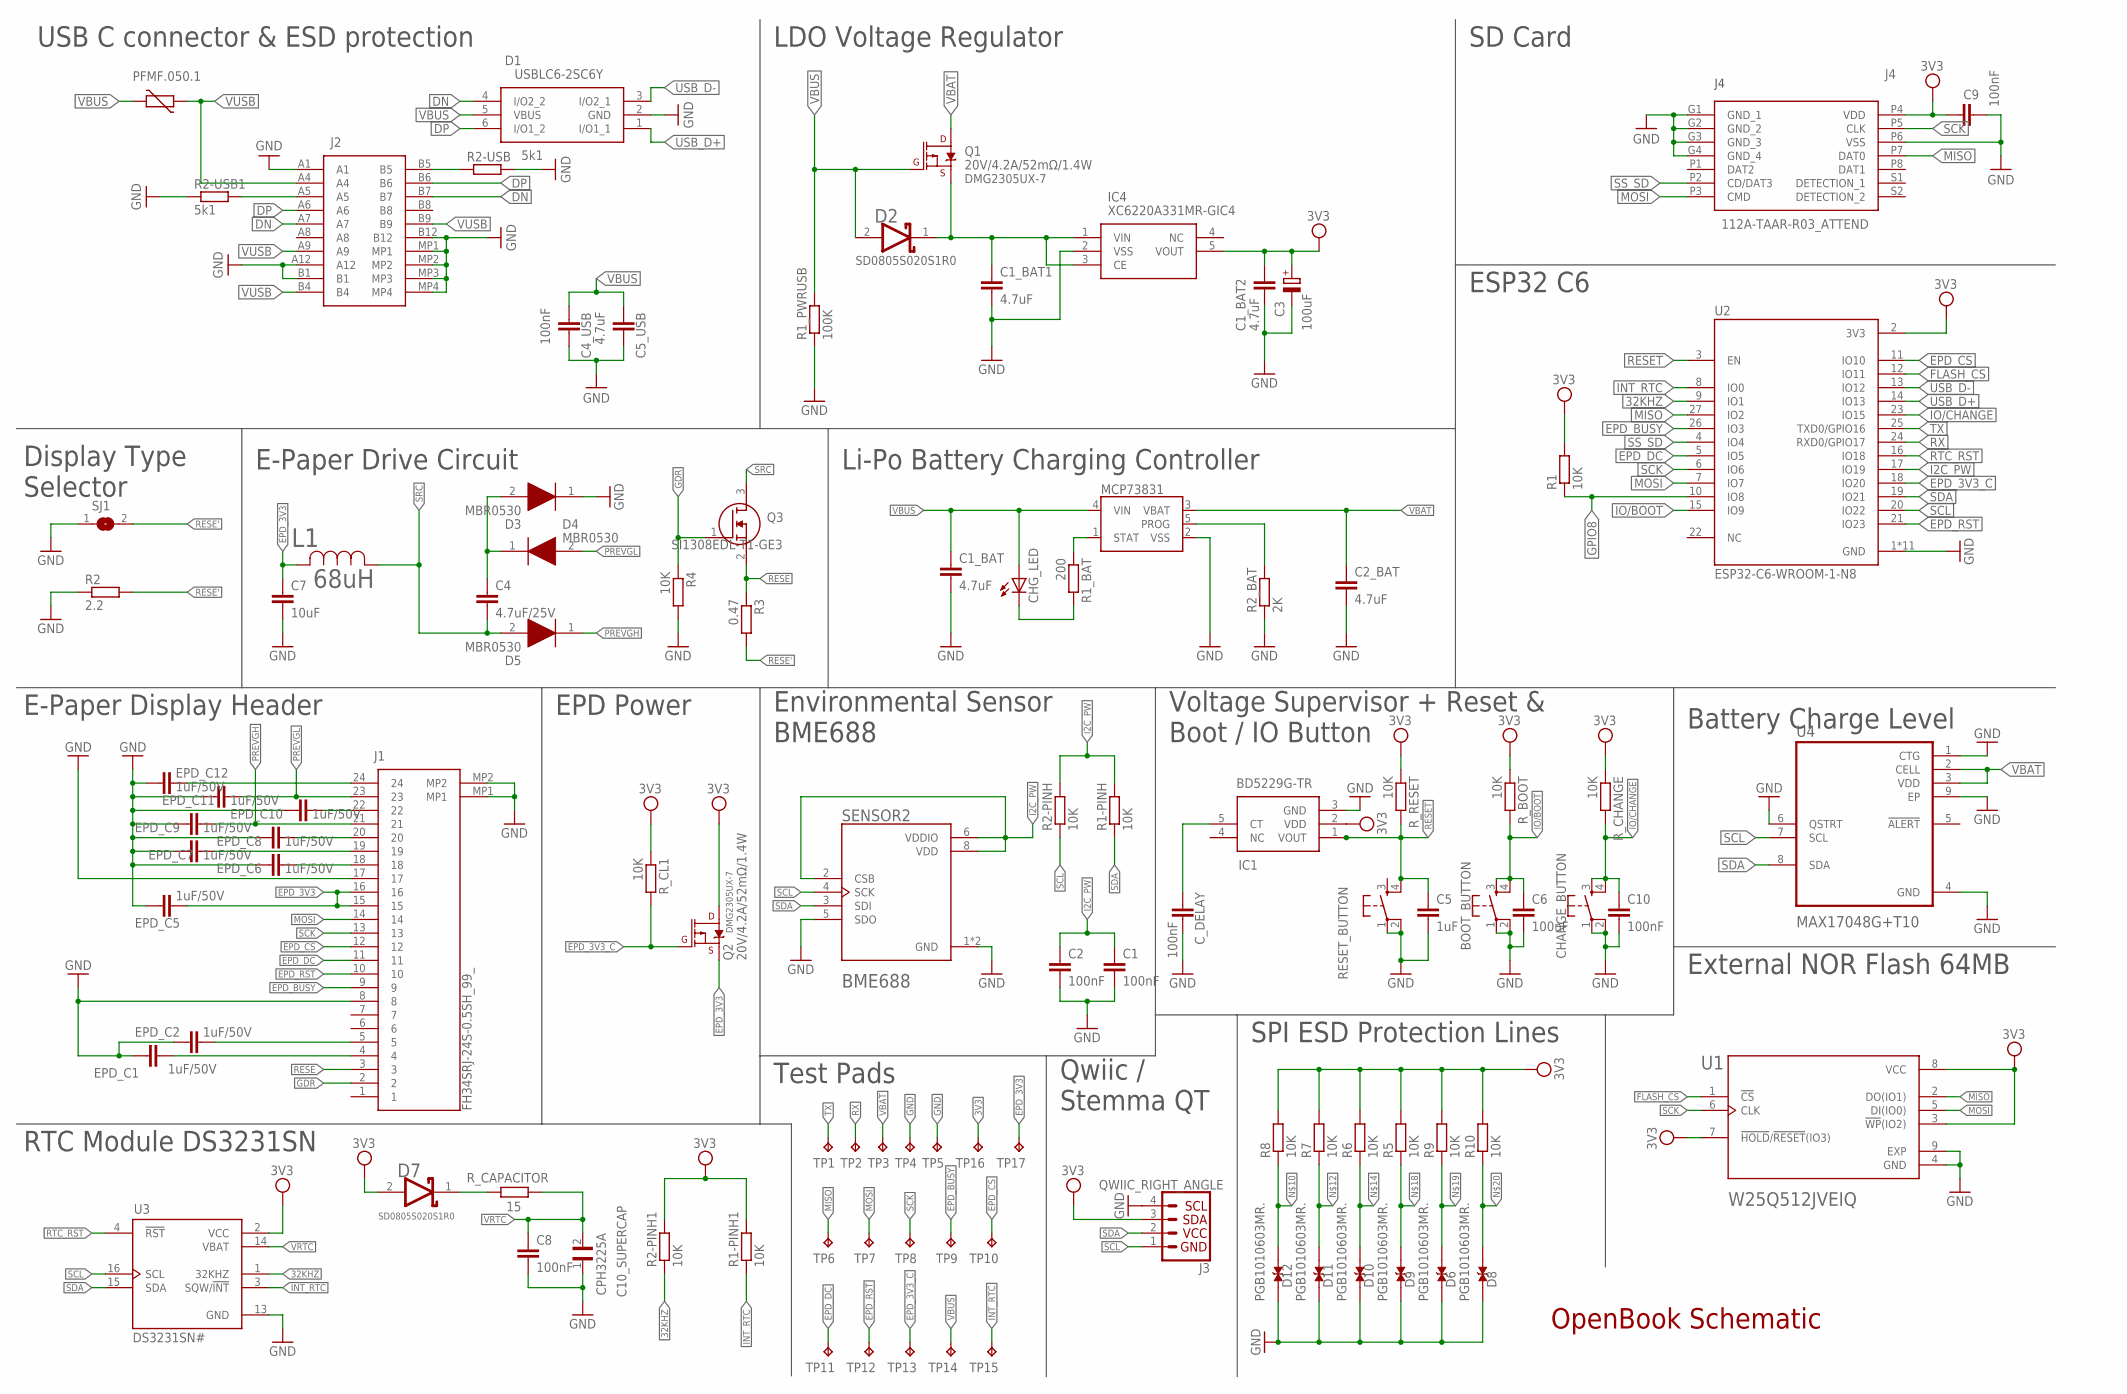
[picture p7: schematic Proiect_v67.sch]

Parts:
BOOT_BUTTON: BUTTON_CUSYOMV1.; MYBUTTON
C1, C2, C4_USB, C6, C8, C9, C10: 100nF; EAGLE-LTSPICE_C0402
C1_BAT, C1_BAT1, C1_BAT2, C2_BAT, C5_USB: 4.7uF; EAGLE-LTSPICE_C0402
C3: 100uF; RCL_CT3528
C4: 4.7uF/25V; EAGLE-LTSPICE_C0402
C5: 1uF; EAGLE-LTSPICE_C0402
C7: 10uF; EAGLE-LTSPICE_C0402
C10_SUPERCAP: CPH3225A; CAPCP3225X100N
CHANGE_BUTTON: BUTTON_CUSYOMV1.; MYBUTTON
CHG_LED: ADAFRUIT_LEDCHIP-LED0603; ADAFRUIT_CHIP-LED0603
C_DELAY: 100nF; EAGLE-LTSPICE_C0402
D1: USBLC6-2SC6Y; SOT95P280X145-6N
D2, D7: ESP32_WROVER_AVX---SD0805S020S1R0_AVX_SD0805S020S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; ESP32_WROVER_AVX---SD0805S020S1R0_AVX_SD0805S020S1R0_0
D3, D4, D5: MBR0530; SOD3716X135N
D6, D8, D9, D10, D11, D12: PGB1010603MR.; DIOC1608X36N
EPD_C1, EPD_C2, EPD_C5, EPD_C6, EPD_C7, EPD_C8, EPD_C9, EPD_C10, EPD_C11, EPD_C12: 1uF/50V; EAGLE-LTSPICE_C0402
IC1: BD5229G-TR; SOT95P280X125-5N
IC4: XC6220A331MR-GIC4; SOT95P280X120-5N
J1: FH34SRJ-24S-0.5SH_99_; FH34SRJ24S05SH99
J2: SAMACSYS_PARTS_USB4110-GF-A; SAMACSYS_PARTS_USB4110GFA
J3: QWIIC_RIGHT_ANGLE; JST04_1MM_RA
J4: 112A-TAAR-R03_ATTEND; 112ATAARR03ATTEND
L1: 68uH; IND_4828-WE-TPC_WRE
MCP73831: ESP32_WROVER_SPARKFUN-IC-POWER_MCP73831; ESP32_WROVER_SPARKFUN-IC-POWER_SOT23-5
PFMF.050.1: ESP32C6_VARISTORCN1812; ESP32C6_VARISTOR_CT/CN1812
Q1, Q2: 20V/4.2A/52mΩ/1.4W; ESP32_WROVER_SPARKFUN-DISCRETESEMI_SOT23-3
Q3: SI1308EDL-T1-GE3; SOT65P210X110-3N
R1, R1-PINH, R1-PINH1, R2-PINH, R2-PINH1, R4, R5, R6, R7, R8, R9, R10: 10K; ESP32_WROVER_EAGLE-LTSPICE_R0402
R1_BAT: 200; ESP32_WROVER_EAGLE-LTSPICE_R0402
R1_PWRUSB: 100K; ESP32_WROVER_EAGLE-LTSPICE_R0402
R2: 2.2; ESP32_WROVER_EAGLE-LTSPICE_R0402
R2-USB, R2-USB1: 5k1; ESP32_WROVER_EAGLE-LTSPICE_R0402
R2_BAT: 2K; ESP32_WROVER_EAGLE-LTSPICE_R0402
R3: 0.47; ESP32_WROVER_EAGLE-LTSPICE_R0402
RESET_BUTTON: BUTTON_CUSYOMV1.; MYBUTTON
R_BOOT: 10K; ESP32_WROVER_EAGLE-LTSPICE_R0402
R_CAPACITOR: 15; ESP32_WROVER_EAGLE-LTSPICE_R0402
R_CHANGE: 10K; ESP32_WROVER_EAGLE-LTSPICE_R0402
R_CL1: 10K; ESP32_WROVER_EAGLE-LTSPICE_R0402
R_RESET: 10K; ESP32_WROVER_EAGLE-LTSPICE_R0402
SENSOR2: ESP32_WROVER_BME680_BME680; ESP32_WROVER_BME680_PSON80P300X300X100-8N
SJ1: SJ
TP1, TP2, TP3, TP4, TP5, TP6, TP7, TP8, TP9, TP10, TP11, TP12, TP13, TP14, TP15, TP16, TP17: TPTP20R; TP20R
U1: W25Q512JVEIQ; SON127P600X800X80-9N
U2: ESP32-C6-WROOM-1-N8; XCVR_ESP32-C6-WROOM-1-N8
U3: DS3231SN#; SOIC127P1032X265-16N
U4: MAX17048G+T10; SON50P200X200X80-9N

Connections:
3V3: C1_BAT2.1, C3.+, C9.1, D7.2 (ANODE), IC1.2 (VDD), IC4.5 (VOUT), J3.3, J4.P4 (VDD), Q2.3 (D), R1.2, R1-PINH1.2, R2-PINH1.2, R5.2, R6.2, R7.2, R8.2, R9.2, R10.2, R_BOOT.1, R_CHANGE.1, R_CL1.1, R_RESET.1, TP16.TP, U1.3 (!WP!(IO2)), U1.7 (!HOLD!/!RESET!(IO3)), U1.8 (VCC), U2.2 (3V3), U3.2 (VCC)
32KHZ: R2-PINH1.1, U2.9 (IO1), U3.1 (32KHZ)
DN: D1.4 (I/O2_2), J2.A7, J2.B7
DP: D1.6 (I/O1_2), J2.A6, J2.B6
EPD_3V3: C7.1, EPD_C5.1, J1.15, J1.16, L1.2, Q2.2 (S), TP17.TP
EPD_3V3_C: Q2.1 (G), R_CL1.2, TP13.TP, U2.18 (IO20)
EPD_BUSY: J1.9, TP9.TP, U2.26 (IO3)
EPD_CS: J1.12, TP10.TP, U2.11 (IO10)
EPD_DC: J1.11, TP11.TP, U2.5 (IO5)
EPD_RST: J1.10, TP12.TP, U2.21 (IO23)
FLASH_CS: U1.1 (!CS), U2.12 (IO11)
GDR: J1.2, Q3.1 (G), R4.1
GND: BOOT_BUTTON.1, BOOT_BUTTON.2, C1.2, C1_BAT.2, C1_BAT1.2, C1_BAT2.2, C2.2, C2_BAT.2, C3.-, C4_USB.2, C5.2, C5_USB.2, C6.2, C7.2, C8.2, C9.2, C10.2, C10_SUPERCAP.1, CHANGE_BUTTON.1, CHANGE_BUTTON.2, C_DELAY.2, D1.2 (GND), D3.1 (K), D6.1, D8.1, D9.1, D10.1, D11.1, D12.1, EPD_C1.2, EPD_C2.2, EPD_C5.2, EPD_C6.2, EPD_C7.2, EPD_C8.2, EPD_C9.2, EPD_C10.2, EPD_C11.2, EPD_C12.2, IC1.3 (GND), IC4.2 (VSS), J1.8, J1.17, J1.MP1, J1.MP2, J2.A1, J2.A12, J2.B1, J2.B12, J2.MP1, J2.MP2, J2.MP3, J2.MP4, J3.4, J4.G1 (GND_1), J4.G2 (GND_2), J4.G3 (GND_3), J4.G4 (GND_4), J4.P6 (VSS), MCP73831.2 (VSS), R1_PWRUSB.1, R2.1, R2-USB.2, R2-USB1.1, R2_BAT.1, R4.2, RESET_BUTTON.1, RESET_BUTTON.2, SENSOR2.1 (GND), SENSOR2.5 (SDO), SENSOR2.7 (GND), SJ1.1, TP4.TP, TP5.TP, U1.4 (GND), U1.9 (EXP), U2.1 (GND), U2.28 (GND), U2.29_1 (GND), U2.29_2 (GND), U2.29_3 (GND), U2.29_4 (GND), U2.29_5 (GND), U2.29_6 (GND), U2.29_7 (GND), U2.29_8 (GND), U2.29_9 (GND), U3.13 (GND), U4.1 (CTG), U4.4 (GND), U4.6 (QSTRT), U4.9 (EP)
GPIO8: R1.1, U2.10 (IO8)
I2C_PW: C1.1, C2.1, R1-PINH.2, R2-PINH.2, SENSOR2.2 (CSB), SENSOR2.6 (VDDIO), SENSOR2.8 (VDD), U2.17 (IO19)
INT_RTC: R1-PINH1.1, TP15.TP, U2.8 (IO0), U3.3 (SQW/!INT)
IO/BOOT: BOOT_BUTTON.3, BOOT_BUTTON.4, C6.1, R_BOOT.2, U2.15 (IO9)
IO/CHANGE: C10.1, CHANGE_BUTTON.3, CHANGE_BUTTON.4, R_CHANGE.2, U2.23 (IO15)
MISO: J4.P7 (DAT0), TP6.TP, U1.2 (DO(IO1)), U2.27 (IO2)
MOSI: J1.14, J4.P3 (CMD), TP7.TP, U1.5 (DI(IO0)), U2.7 (IO7)
unnamed: J2.B5, R2-USB.1
unnamed: C_DELAY.1, IC1.5 (CT)
unnamed: EPD_C12.1, J1.24
unnamed: C1_BAT1.1, D2.1 (CATHODE), IC4.1 (VIN), IC4.3 (CE), Q1.2 (S)
unnamed: MCP73831.5 (PROG), R2_BAT.2
unnamed: CHG_LED.C, R1_BAT.2
unnamed: MCP73831.1 (STAT), R1_BAT.1
unnamed: C4.1, D3.2 (A), D4.1 (K)
unnamed: D12.2, R8.1
unnamed: J2.A5, R2-USB1.2
unnamed: D11.2, R7.1
unnamed: EPD_C10.1, J1.22
unnamed: D10.2, R6.1
unnamed: EPD_C8.1, J1.20
unnamed: EPD_C7.1, J1.19
unnamed: EPD_C6.1, J1.18
unnamed: D9.2, R5.1
unnamed: D6.2, R9.1
unnamed: D8.2, R10.1
unnamed: D7.1 (CATHODE), R_CAPACITOR.2
unnamed: EPD_C2.1, J1.5
unnamed: EPD_C1.1, J1.4
PREVGH: D5.1 (K), EPD_C9.1, J1.21
PREVGL: D4.2 (A), EPD_C11.1, J1.23
RESE: J1.3, Q3.2 (S), R3.1
RESE': R2.2, R3.2, SJ1.2
RESET: C5.1, IC1.1 (VOUT), RESET_BUTTON.4, R_RESET.2, U2.3 (EN)
RTC_RST: U2.16 (IO18), U3.4 (!RST)
RX: TP2.TP, U2.24 (RXD0/GPIO17)
SCK: J1.13, J4.P5 (CLK), TP8.TP, U1.6 (CLK), U2.6 (IO6)
SCL: J3.1, R2-PINH.1, SENSOR2.4 (SCK), U2.20 (IO22), U3.16 (SCL), U4.7 (SCL)
SDA: J3.2, R1-PINH.1, SENSOR2.3 (SDI), U2.19 (IO21), U3.15 (SDA), U4.8 (SDA)
SRC: C4.2, D5.2 (A), L1.1, Q3.3 (D)
SS_SD: J4.P2 (CD/DAT3), U2.4 (IO4)
TX: TP1.TP, U2.25 (TXD0/GPIO16)
USB_D+: D1.1 (I/O1_1), U2.14 (IO13)
USB_D-: D1.3 (I/O2_1), U2.13 (IO12)
VBAT: C2_BAT.1, MCP73831.3 (VBAT), Q1.3 (D), TP3.TP, U4.2 (CELL), U4.3 (VDD)
VBUS: C1_BAT.1, C4_USB.1, C5_USB.1, CHG_LED.A, D1.5 (VBUS), D2.2 (ANODE), MCP73831.4 (VIN), PFMF.050.1.2, Q1.1 (G), R1_PWRUSB.2, TP14.TP
VRTC: C8.1, C10_SUPERCAP.2, R_CAPACITOR.1, U3.14 (VBAT)
VUSB: J2.A4, J2.A9, J2.B4, J2.B9, PFMF.050.1.1

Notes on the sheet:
USB C connector & ESD protection
LDO Voltage Regulator
SD Card
ESP32 C6
Battery Charge Level
Voltage Supervisor + Reset & Boot / IO Button
Environmental Sensor BME688
EPD Power
E-Paper Display Header
Display Type Selector
E-Paper Drive Circuit
Li-Po Battery Charging Controller
RTC Module DS3231SN
Test Pads
Qwiic / Stemma QT
SPI ESD Protection Lines
External NOR Flash 64MB
OpenBook Schematic

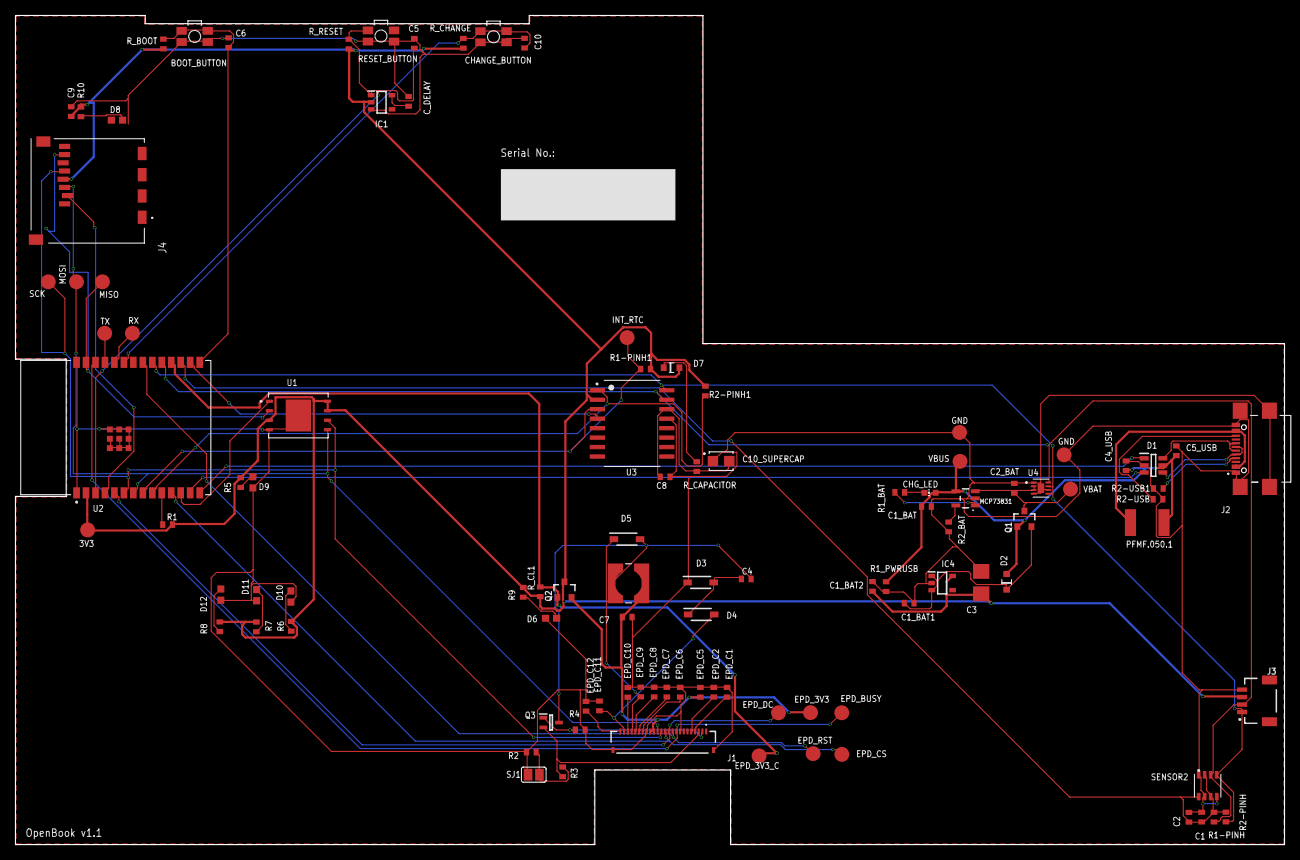
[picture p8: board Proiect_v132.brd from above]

Board: 2 copper layers, 170.2 x 111.2 mm, 103 parts (0 on the bottom side), 61 nets.

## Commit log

2025-04-06 am adaugat Hardware
    [Proiect v121.brd, Proiect_v67.sch]
2025-04-06 am adaugat si restul folderelor
    [BOM.csv, Pick_and_Place.csv]
2025-04-11 am rezolvat issue-urile si am adaugat fisierele
    [Proiect_v132.brd]

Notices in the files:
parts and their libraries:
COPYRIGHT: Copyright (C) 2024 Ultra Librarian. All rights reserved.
